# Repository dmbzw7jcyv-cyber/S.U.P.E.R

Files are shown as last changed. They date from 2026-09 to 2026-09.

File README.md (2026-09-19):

# S.U.P.E.R.

## Smart USB Peripheral Enclosure Rack

S.U.P.E.R. is a 3D-printable rack for **ten Crucial X10-sized portable SSDs**. It works as plain passive storage with zero electronics, then upgrades into a temperature-controlled rack using an Arduino Nano R4, a 120 mm PWM fan, temperature sensors, fan RPM monitoring, and optional physical SSD-presence switches.

Every SSD sits horizontally with its **USB-C port facing forward**, so a drive can remain in the rack while connected.

## v1 features

- 10 horizontal SSD bays in a 2 x 5 layout
- front-facing USB-C access
- finger-access openings
- rear mount for a standard 120 mm fan
- large airflow paths around the SSD matrix
- upper service compartment sized for an Arduino Nano R4
- hidden wiring channels
- optional removable microswitch carriers for bay detection
- optional rear fan grille
- removable electronics lid
- fully functional passive mode with no electronics installed

## Approximate size

The printed main body is about **124 x 124 x 80 mm**. A standard 25 mm-thick rear fan brings total depth to about **105 mm**.

## Reference electronics

- Arduino Nano R4
- Noctua NF-P12 redux-1700 PWM
- 1 to 3 DS18B20 temperature sensors
- 10 normally-open submini lever microswitches
- regulated 12 V power supply

## Repository layout

```text
S.U.P.E.R/
├── README.md
├── BOM.md
├── cad/
│   └── SUPER_v1.scad
├── stl/
│   ├── SUPER_main.stl
│   ├── SUPER_lid.stl
│   ├── SUPER_switch_carrier.stl
│   └── SUPER_fan_grille.stl
├── firmware/
│   └── SUPER_Controller/
│       └── SUPER_Controller.ino
└── docs/
    ├── WIRING.md
    └── PRINTING.md
```

The GitHub Action in `.github/workflows/build-stls.yml` regenerates the STL files from the OpenSCAD source.

## Build order

1. Print the main rack and lid.
2. Test a real X10 in several bays before installing electronics.
3. Mount the 120 mm fan on the rear as exhaust.
4. Install the Nano R4 in the upper service bay.
5. Wire fan power, PWM and tach according to `docs/WIRING.md`.
6. Add DS18B20 sensors and the required 4.7 kOhm pull-up.
7. If wanted, print two switch carriers and install the ten presence switches.
8. In Arduino IDE Library Manager, install **OneWire** and **DallasTemperature**.
9. Open `firmware/SUPER_Controller/SUPER_Controller.ino`.
10. Select **Arduino Nano R4**, compile and upload.
11. Open Serial Monitor at **115200 baud**.

## Default cooling curve

| Hottest sensor | Fan command |
|---|---:|
| <= 35 C | 0% |
| 35-40 C | 25% |
| 40-45 C | 50% |
| 45-50 C | 75% |
| > 50 C | 100% |

If temperature sensing fails, v1 commands **100% fan speed** as a fail-safe.

These are project defaults, not manufacturer thermal limits. Tune them only after testing your own enclosure, room temperature and workloads.

## Fan-control design

The fan is powered directly from the 12 V supply. **Do not power the fan from a Nano GPIO pin.** Nano D3 controls the blue PWM lead through a 2N2222/PN2222A NPN transistor used as an open-collector driver. The firmware generates a 25 kHz PWM waveform using the Nano R4 Renesas PWM API.

The fan green tach lead is read on D2 so the controller can report RPM.

## Bay detection

Each bay can press a normally-open microswitch when a drive is fully inserted. The switches share a ground bus and use the Nano's internal pull-ups.

This detects **physical presence only**. v1 does not inspect the SSD filesystem, SMART data, drive name, capacity or USB activity.

## Passive mode

Don't want to wire anything yet? Print the main rack and lid and use it immediately. The fan, Nano, temperature sensors and bay switches are optional upgrades and do not form part of the structural SSD slots.

## CAD

The editable source is `cad/SUPER_v1.scad`.

```bash
openscad -D 'part="main"' -o SUPER_main.stl cad/SUPER_v1.scad
openscad -D 'part="lid"' -o SUPER_lid.stl cad/SUPER_v1.scad
openscad -D 'part="switch_carrier"' -o SUPER_switch_carrier.stl cad/SUPER_v1.scad
openscad -D 'part="fan_grille"' -o SUPER_fan_grille.stl cad/SUPER_v1.scad
```

## Hardware references

- Arduino Nano R4: https://docs.arduino.cc/hardware/nano-r4/
- Noctua NF-P12 redux-1700 PWM: https://www.noctua.at/en/products/nf-p12-redux-1700-pwm
- Noctua PWM microcontroller guide: https://www.noctua.at/en/support/faqs/microcontroller-guide-pwm-setup-and-rpm-monitoring
- Crucial X10: https://www.crucial.com/ssd/x10

## Prototype warning

**v1 is a prototype design.** Measure your exact SSDs, switches, connectors and printed fit before assembling the complete electronics package. Insulate all connections, verify polarity with a multimeter, confirm the fan fail-safe works, and do not leave an early prototype powered unattended.

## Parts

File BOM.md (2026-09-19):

# S.U.P.E.R. v1 bill of materials

## Required for passive storage

| Qty | Part | Notes |
|---:|---|---|
| 1 | Printed `SUPER_main.stl` | Holds ten Crucial X10-sized portable SSDs |
| 1 | Printed `SUPER_lid.stl` | Covers the top electronics bay even if unused |

That is all you need if you only want the storage rack.

## Smart cooling upgrade

| Qty | Part | Notes |
|---:|---|---|
| 1 | Arduino Nano R4 with headers | Main controller |
| 1 | Noctua NF-P12 redux-1700 PWM | 120 mm, 12 V, 4-pin PWM fan |
| 1 | 12 V regulated supply, >=1 A | Powers fan and Nano VIN |
| 1 | 5.5 x 2.1 mm DC jack breakout | Or another suitable keyed connector |
| 1 | 2N2222 / PN2222A NPN transistor | Open-collector PWM interface |
| 1 | 1 kOhm resistor | Nano D3 to transistor base |
| 1 | 10 kOhm resistor | Transistor base pulldown |
| 1 | 4.7 kOhm resistor | DS18B20 data pull-up |
| 1 | 10 kOhm resistor | Optional external fan tach pull-up |
| 1-3 | DS18B20 sensors | Three zones recommended |
| 10 | Normally-open submini lever microswitches | Optional bay-presence detection |
| 2 | Printed switch carriers | One per five bays |
| 1 | Printed fan grille | Optional |
| 1 roll | 24-28 AWG hookup wire | Multiple colors strongly recommended |
| as needed | Heat shrink / crimp connectors | Insulate every exposed joint |

## Optional assembly hardware

- Four M4 machine screws + nuts long enough for your chosen fan/grille stack, or the fan's included mounting screws when appropriate
- Small JST-style connectors if you want the fan, sensors, and switch carriers to unplug cleanly
- Adhesive rubber feet for the bottom of the rack
- 1 A inline fuse on the 12 V input for extra protection

## Notes

The printed switch carrier targets switches around **12.8 x 6.5 x 6.5 mm**. Buy the switches first if possible and measure them with calipers before printing the carriers.

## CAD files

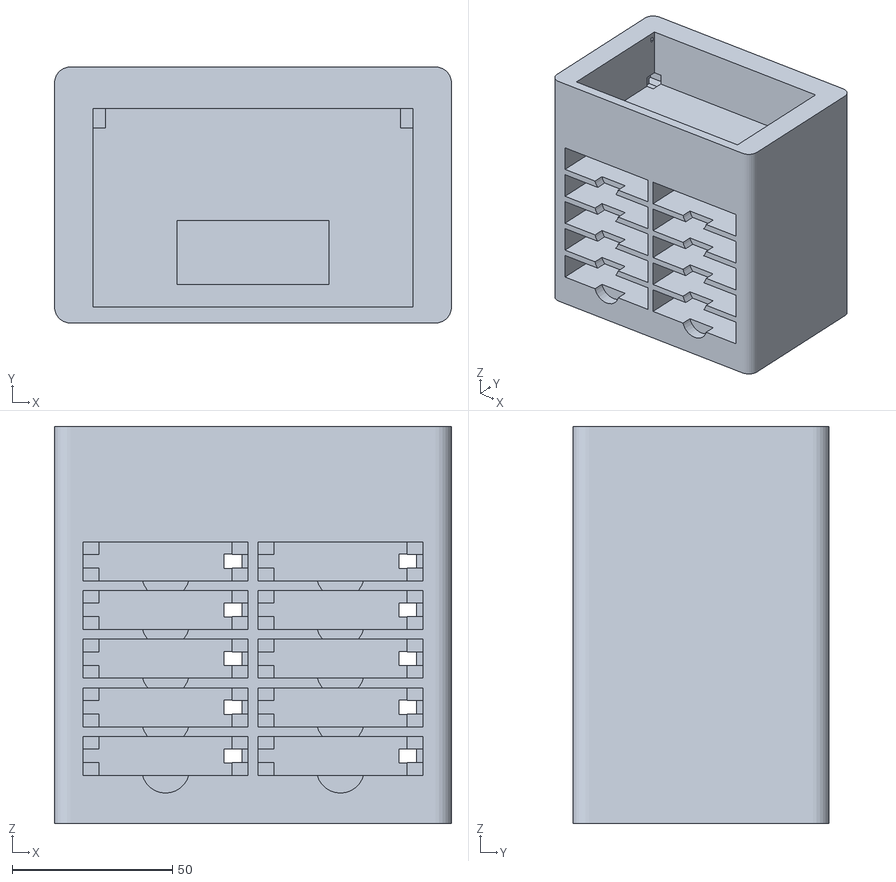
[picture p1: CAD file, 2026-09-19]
stl/SUPER_main.stl
124.0 x 80.0 x 124.0

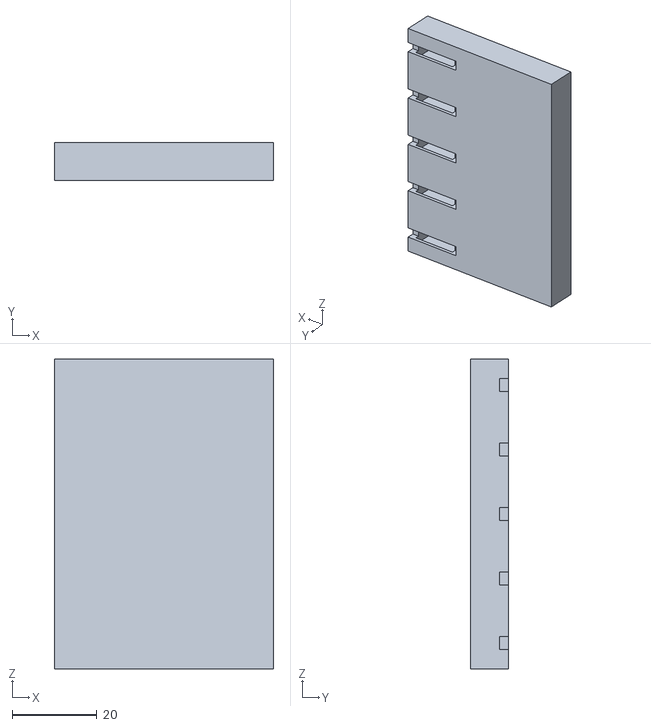
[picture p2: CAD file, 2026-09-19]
stl/SUPER_switch_carrier.stl
51.6 x 9.00 x 73.0

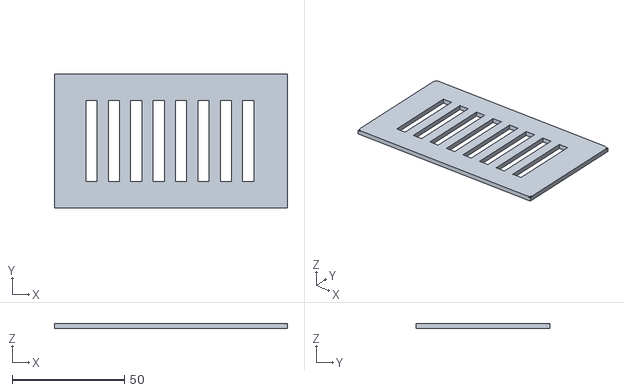
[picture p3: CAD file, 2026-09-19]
stl/SUPER_lid.stl
104.0 x 60.0 x 2.20

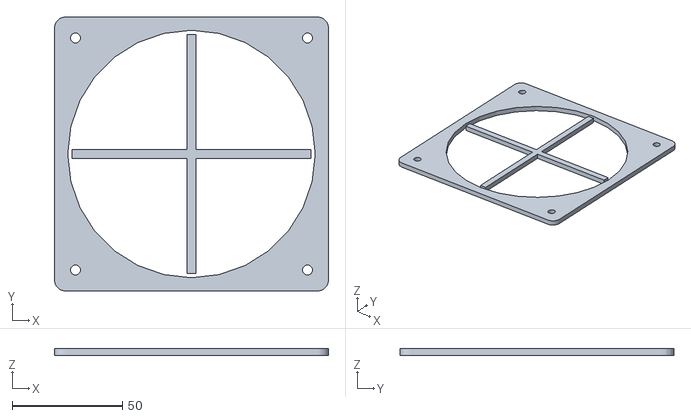
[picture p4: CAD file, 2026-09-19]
stl/SUPER_fan_grille.stl
124.0 x 124.0 x 3.00

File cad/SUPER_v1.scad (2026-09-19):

// S.U.P.E.R. v1
// Smart USB Peripheral Enclosure Rack
// 10 Crucial X10-sized SSD bays + optional Nano R4 smart cooling.
// Units: mm.
//
// Select part:
// openscad -D 'part="main"' -o SUPER_main.stl SUPER_v1.scad
// Parts: main, lid, switch_carrier, fan_grille

$fn = 28;
part = "main";

ssd_w = 50.0;
ssd_h = 10.0;
ssd_d = 65.0;
clear_w = 1.6;
clear_h = 2.2;
clear_d = 2.0;
bay_w = ssd_w + clear_w;
bay_h = ssd_h + clear_h;
bay_d = ssd_d + clear_d;

cols = 2;
rows = 5;
outer_w = 124;
outer_h = 124;
outer_d = 80;
wall = 3;
center_div = 3;
shelf = 3;
bay_stack_h = rows*bay_h + (rows-1)*shelf;
bay_x0 = (outer_w - (2*bay_w + center_div))/2;
bay_z0 = 15;

fan_hole_spacing = 105;
fan_hole_d = 4.5;
fan_center_x = outer_w/2;
fan_center_z = outer_h/2;

elec_z0 = 96;
elec_h = 25;
elec_y0 = 5;
elec_depth = 62;
nano_pocket_l = 47.5;
nano_pocket_w = 20.0;
nano_pocket_h = 9.0;
usb_cut_w = 12;
usb_cut_h = 8;

switch_body_l = 13.2;
switch_body_w = 7.0;
switch_body_h = 7.0;
carrier_w = bay_w;
carrier_d = 9;
carrier_h = bay_stack_h;

module rounded_box(size=[10,10,10], r=2) {
    linear_extrude(height=size[2])
        offset(r=r)
            offset(delta=-r)
                square([size[0], size[1]]);
}

module bay_cut(x,z) {
    translate([x, -0.2, z]) cube([bay_w, bay_d, bay_h]);

    translate([x + bay_w/2, 5.5, z + 2.0])
        rotate([90,0,0]) cylinder(h=6, r=7.5);

    translate([x+3, bay_d-0.1, z+2])
        cube([bay_w-6, outer_d-bay_d+0.3, bay_h-4]);

    translate([x + bay_w - 7.5, bay_d-0.6, z + bay_h/2 - 2.2])
        cube([5.5, 4.0, 4.4]);
}

module rear_stop_tabs(x,z) {
    tab_w = 5;
    tab_d = 4;
    tab_h = 4;
    translate([x-0.6, bay_d-tab_d, z])
        cube([tab_w+0.6,tab_d,tab_h]);
    translate([x+bay_w-tab_w, bay_d-tab_d, z])
        cube([tab_w+0.6,tab_d,tab_h]);
    translate([x-0.6, bay_d-tab_d, z+bay_h-tab_h])
        cube([tab_w+0.6,tab_d,tab_h]);
    translate([x+bay_w-tab_w, bay_d-tab_d, z+bay_h-tab_h])
        cube([tab_w+0.6,tab_d,tab_h]);
}

module fan_mount_holes() {
    for (sx=[-1,1], sz=[-1,1]) {
        x = fan_center_x + sx*fan_hole_spacing/2;
        z = fan_center_z + sz*fan_hole_spacing/2;
        translate([x, outer_d-8, z])
            rotate([-90,0,0]) cylinder(h=10,d=fan_hole_d);
    }
}

module wire_channels() {
    for (x=[3.5, outer_w-7.5]) {
        translate([x, bay_d+1, bay_z0-1])
            cube([4, outer_d-bay_d-2, bay_stack_h+4]);
    }
    translate([3.5, bay_d+1, elec_z0-4])
        cube([outer_w-7, outer_d-bay_d-2, 4]);
}

module electronics_cut() {
    translate([12, elec_y0, elec_z0])
        cube([outer_w-24, elec_depth, elec_h+5]);

    translate([outer_w/2 - nano_pocket_l/2,
               elec_y0 + 7,
               elec_z0 - 0.2])
        cube([nano_pocket_l, nano_pocket_w, nano_pocket_h]);

    translate([-0.2, elec_y0 + 12, elec_z0 + 7])
        cube([wall+1, usb_cut_w, usb_cut_h]);

    translate([8, elec_y0+elec_depth-6, elec_z0-3])
        cube([8,8,8]);
    translate([outer_w-16, elec_y0+elec_depth-6, elec_z0-3])
        cube([8,8,8]);
}

module lid_rails_cut() {
    translate([10, elec_y0+1, elec_z0+elec_h-1.6])
        cube([outer_w-20,1.8,2.2]);
    translate([10, elec_y0+elec_depth-2.8, elec_z0+elec_h-1.6])
        cube([outer_w-20,1.8,2.2]);
}

module main_rack() {
    difference() {
        rounded_box([outer_w,outer_d,outer_h], 5);

        for (r=[0:rows-1]) for (c=[0:cols-1]) {
            x = bay_x0 + c*(bay_w+center_div);
            z = bay_z0 + r*(bay_h+shelf);
            bay_cut(x,z);
        }

        translate([2.5,10,bay_z0+4])
            cube([bay_x0-4.5, outer_d-20, bay_stack_h-8]);
        translate([bay_x0+2*bay_w+center_div+2,10,bay_z0+4])
            cube([outer_w-(bay_x0+2*bay_w+center_div)-4.5,
                  outer_d-20,
                  bay_stack_h-8]);

        translate([bay_x0+1,bay_d-0.1,bay_z0+1])
            cube([2*bay_w+center_div-2,
                  outer_d-bay_d+0.3,
                  bay_stack_h-2]);

        wire_channels();
        electronics_cut();
        lid_rails_cut();
        fan_mount_holes();
    }

    for (r=[0:rows-1]) for (c=[0:cols-1]) {
        x = bay_x0 + c*(bay_w+center_div);
        z = bay_z0 + r*(bay_h+shelf);
        rear_stop_tabs(x,z);
    }
}

module electronics_lid() {
    lid_w = outer_w-20;
    lid_d = elec_depth-2;
    lid_t = 2.2;
    difference() {
        rounded_box([lid_w,lid_d,lid_t],2);
        for (i=[0:7])
            translate([14+i*10,12,-0.2])
                cube([5,lid_d-24,lid_t+0.4]);
    }
    translate([0,0,0]) cube([lid_w,1.4,1.8]);
    translate([0,lid_d-1.4,0]) cube([lid_w,1.4,1.8]);
}

module switch_carrier() {
    difference() {
        cube([carrier_w, carrier_d, carrier_h]);
        for (r=[0:rows-1]) {
            z = r*(bay_h+shelf) + (bay_h-switch_body_h)/2;
            translate([carrier_w-switch_body_l-2, 1.0, z])
                cube([switch_body_l, switch_body_w, switch_body_h]);
            translate([carrier_w-switch_body_l-4, carrier_d-2.2, z+2.0])
                cube([switch_body_l+4, 2.5, 3.0]);
        }
        translate([2,2,2])
            cube([3,carrier_d-3,carrier_h-4]);
    }
}

module fan_grille() {
    g=124;
    t=3;
    difference() {
        rounded_box([g,g,t],5);
        translate([g/2,g/2,-0.2])
            cylinder(h=t+0.4,d=112);
        for (sx=[-1,1], sy=[-1,1]) {
            x = g/2 + sx*fan_hole_spacing/2;
            y = g/2 + sy*fan_hole_spacing/2;
            translate([x,y,-0.2])
                cylinder(h=t+0.4,d=fan_hole_d);
        }
    }
    translate([g/2-2,8,0]) cube([4,g-16,t]);
    translate([8,g/2-2,0]) cube([g-16,4,t]);
}

if (part == "main") main_rack();
else if (part == "lid") electronics_lid();
else if (part == "switch_carrier") switch_carrier();
else if (part == "fan_grille") fan_grille();
else main_rack();

// STL build trigger: v1

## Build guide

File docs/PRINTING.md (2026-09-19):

# Printing and assembly

## Files

- `stl/SUPER_main.stl` - main 10-bay rack and rear fan mount
- `stl/SUPER_lid.stl` - electronics-compartment lid
- `stl/SUPER_switch_carrier.stl` - optional five-switch carrier; print two
- `stl/SUPER_fan_grille.stl` - optional rear fan guard
- `cad/SUPER_v1.scad` - editable source

## Main dimensions

The body is approximately **124 x 124 x 80 mm**. A 25 mm-thick 120 mm fan mounted on the rear brings total depth to about **105 mm**.

The current SSD cavities use an approximately **65 x 50 x 10 mm** X10 envelope plus print and airflow clearance. Verify against your own drive before a long print.

## Suggested settings

- Material: PETG preferred; PLA+ is fine for ordinary indoor temperatures
- Layer height: 0.20 mm
- Walls/perimeters: 4
- Top/bottom layers: 4 or 5
- Infill: 15 to 25%
- Nozzle: 0.4 mm

For the main body, orient the model so the **front face is on the build plate**. This makes the long SSD cavities build vertically rather than requiring giant horizontal bridges.

The smaller parts can print flat on their largest face.

## Fit-test first

Printers vary. Before committing to the full rack, make a small one-bay test or crop the model in your slicer. An X10 should slide in without force but should not rattle dramatically.

If your printer runs tight, increase `clear_w` and `clear_h` in `cad/SUPER_v1.scad` by about 0.2 to 0.4 mm.

## Fan orientation

Mount the fan at the rear as **exhaust**. It should pull room air through the open front/side passages, across the SSDs, and out the back.

The model uses a standard **105 x 105 mm** 120 mm fan mounting pattern.

## Electronics bay

The top service compartment is separate from the SSD tunnels and includes:

- Nano-R4-sized pocket
- side USB-C programming opening
- wiring pass-throughs to the rear cable spines
- removable vented lid

The rack still works with this compartment totally empty.

## Presence sensors

Print **two** switch carriers if you want smart bay detection. Each holds five switches.

Microswitch dimensions vary by manufacturer. If yours do not fit, change only the `switch_body_*` parameters in the SCAD and re-export the carrier.

## Fan grille

The rear grille is optional. If installed, use fasteners long enough for your fan/grille arrangement but never allow screw tips to contact the blades.

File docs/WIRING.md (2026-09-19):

# S.U.P.E.R. wiring guide

The printed rack works as passive storage with **none of this electronics installed**.

## Important electrical rule

**Do not power the 12 V fan from an Arduino GPIO pin or the Nano's 5 V pin.** The fan receives 12 V directly from the power supply. The Nano only controls the PWM lead and reads the tach lead.

The reference fan is the **Noctua NF-P12 redux-1700 PWM**. Noctua specifies it as a 120 x 120 x 25 mm, 12 V, 4-pin PWM fan with 105 mm mounting-hole spacing.

| Fan pin | Noctua wire | Connect to |
|---|---|---|
| 1 | Black | Common GND |
| 2 | Yellow | +12 V supply |
| 3 | Green | Nano D2 (tach) |
| 4 | Blue | Collector of NPN PWM transistor |

## Controller parts

- Arduino Nano R4
- 1x 2N2222 / PN2222A NPN transistor
- 1x 1 kOhm base resistor
- 1x 10 kOhm base pulldown resistor
- 1x optional 10 kOhm tach pull-up to +5 V
- 1x 4.7 kOhm DS18B20 data pull-up
- 1 to 3x DS18B20 temperature sensors
- 10x normally-open submini lever microswitches
- 12 V regulated supply, at least 1 A
- 24 to 28 AWG hookup wire
- heat-shrink tubing or insulated crimp connectors

## Power

The Nano R4 VIN input accepts the 12 V supply used by the reference build.

```text
12 V adapter +  --------------------+---------------- Fan YELLOW (+12 V)
                                    |
                                    +---------------- Nano R4 VIN

12 V adapter GND -------------------+---------------- Fan BLACK (GND)
                                    |
                                    +---------------- Nano R4 GND
                                    |
                                    +---------------- Sensor/switch GND bus
```

All grounds must be common.

If you later add a display, many LEDs, or other accessories, a small 12 V to 5 V buck converter is a good optional upgrade to reduce heat in the Nano's onboard regulator.

## Fan PWM interface

Use an **open-collector NPN stage** rather than connecting the blue PWM wire straight to the GPIO.

```text
Nano D3 ---- 1k ---- B   2N2222
                       C ---------------- Fan BLUE (PWM)
Nano GND -------------- E

10k resistor from B to GND
```

The 10 kOhm pulldown holds the transistor OFF during reset/boot. That lets the fan PWM input float HIGH through the fan's internal circuitry, giving a fail-safe full-speed command while the microcontroller is not actively driving the line.

The firmware outputs approximately **25 kHz PWM** and automatically handles the inversion caused by the NPN stage.

## Fan tach / RPM

```text
Fan GREEN (tach) ---------------- Nano D2
Fan BLACK (ground) -------------- Nano GND

Optional: 10k resistor from D2 to +5 V
```

Noctua specifies the tach output as open-collector with **two cycles per revolution**. The firmware uses that value for RPM calculation.

## Temperature sensors

All DS18B20 sensors share one 1-Wire bus.

```text
DS18B20 VDD   ---------------- +5 V
DS18B20 GND   ---------------- GND
DS18B20 DATA  ---------------- Nano D6

4.7k resistor between DATA and +5 V
```

Suggested sensor locations:

1. lower SSD bank
2. center of the SSD matrix
3. upper/rear exhaust area

The firmware uses the hottest valid sensor reading.

## SSD presence switches

Each bay uses one normally-open microswitch. One terminal of every switch shares ground; the other goes to a dedicated Nano input.

| Bay | Nano pin |
|---|---|
| 1 | D4 |
| 2 | D5 |
| 3 | D7 |
| 4 | D8 |
| 5 | D9 |
| 6 | D10 |
| 7 | D11 |
| 8 | D12 |
| 9 | D13 |
| 10 | A0 |

```text
Nano input ---- microswitch ---- GND
```

The firmware uses `INPUT_PULLUP`:

- switch open = empty bay
- switch pressed = occupied bay

The optional CAD switch carrier targets switches around **12.8 x 6.5 x 6.5 mm**. Measure your actual switches before printing ten of anything.

## SSD data cables

S.U.P.E.R. v1 is **not a USB hub**. Each SSD keeps its own front-facing USB-C port. Connect drives directly to the computer or to a suitable powered USB hub.

The Nano detects physical insertion only. It does not read the drive name, filesystem, SMART health, capacity or USB activity.

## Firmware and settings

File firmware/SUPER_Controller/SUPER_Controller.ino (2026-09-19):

/*
  S.U.P.E.R. Controller
  Smart USB Peripheral Enclosure Rack

  Target: Arduino Nano R4
  Fan: 4-wire 12 V PWM PC fan
  Sensors: up to 3 DS18B20 temperature sensors on one 1-Wire bus
  Bay detection: 10 normally-open microswitches, active LOW with INPUT_PULLUP

  IMPORTANT:
  - The fan's 12 V power does NOT come from the Nano.
  - The Nano controls the fan PWM lead through an NPN open-collector stage.
  - Fan and Nano grounds MUST be common.
  - A 10k base pulldown keeps the transistor OFF while the Nano boots,
    so the fan PWM input floats HIGH and defaults to full speed.
*/

#include <Arduino.h>
#include <OneWire.h>
#include <DallasTemperature.h>
#include "pwm.h"

constexpr uint8_t FAN_PWM_PIN  = D3;
constexpr uint8_t FAN_TACH_PIN = D2;
constexpr uint8_t TEMP_PIN     = D6;

const uint8_t BAY_PINS[10] = {
  D4, D5, D7, D8, D9,
  D10, D11, D12, D13, A0
};

constexpr float FAN_PWM_FREQUENCY_HZ = 25000.0f;
constexpr uint8_t TACH_PULSES_PER_REV = 2;
constexpr uint16_t RPM_SAMPLE_MS = 1000;
constexpr bool FAILSAFE_FULL_SPEED_ON_TEMP_ERROR = true;

constexpr float T0 = 35.0f;
constexpr float T1 = 40.0f;
constexpr float T2 = 45.0f;
constexpr float T3 = 50.0f;

OneWire oneWire(TEMP_PIN);
DallasTemperature tempBus(&oneWire);
PwmOut fanPwm(FAN_PWM_PIN);

volatile uint32_t tachPulses = 0;
uint32_t lastRpmSample = 0;
uint32_t lastStatusPrint = 0;
uint16_t currentRpm = 0;
float currentFanPercent = 100.0f;
float currentMaxTempC = NAN;
uint8_t currentOccupied = 0;

void tachISR() {
  tachPulses++;
}

uint8_t countOccupiedBays() {
  uint8_t count = 0;
  for (uint8_t i = 0; i < 10; ++i) {
    if (digitalRead(BAY_PINS[i]) == LOW) count++;
  }
  return count;
}

float readMaxTemperatureC() {
  tempBus.requestTemperatures();
  const uint8_t count = tempBus.getDeviceCount();
  if (count == 0) return NAN;

  float maxTemp = -1000.0f;
  bool foundValid = false;
  const uint8_t n = (count < 3) ? count : 3;

  for (uint8_t i = 0; i < n; ++i) {
    const float t = tempBus.getTempCByIndex(i);
    if (t != DEVICE_DISCONNECTED_C && t > -55.0f && t < 125.0f) {
      if (t > maxTemp) maxTemp = t;
      foundValid = true;
    }
  }

  return foundValid ? maxTemp : NAN;
}

float fanCurve(float tempC) {
  if (isnan(tempC)) {
    return FAILSAFE_FULL_SPEED_ON_TEMP_ERROR ? 100.0f
                                             : (currentOccupied ? 35.0f : 0.0f);
  }

  if (tempC <= T0) return 0.0f;
  if (tempC <= T1) return 25.0f;
  if (tempC <= T2) return 50.0f;
  if (tempC <= T3) return 75.0f;
  return 100.0f;
}

void setFanPercent(float requestedPercent) {
  requestedPercent = constrain(requestedPercent, 0.0f, 100.0f);

  // NPN stage inverts the logic:
  // Nano HIGH -> transistor ON -> fan PWM lead LOW.
  // Nano LOW  -> transistor OFF -> fan internal pull-up HIGH.
  const float transistorDuty = 100.0f - requestedPercent;
  fanPwm.pulse_perc(transistorDuty);
  currentFanPercent = requestedPercent;
}

void updateRpm() {
  const uint32_t now = millis();
  if (now - lastRpmSample < RPM_SAMPLE_MS) return;

  noInterrupts();
  const uint32_t pulses = tachPulses;
  tachPulses = 0;
  interrupts();

  const float elapsedSeconds = (now - lastRpmSample) / 1000.0f;
  lastRpmSample = now;

  if (elapsedSeconds > 0.0f) {
    currentRpm = (uint16_t)((pulses * 60.0f) /
                            (TACH_PULSES_PER_REV * elapsedSeconds));
  }
}

void printStatus() {
  const uint32_t now = millis();
  if (now - lastStatusPrint < 2000) return;
  lastStatusPrint = now;

  Serial.println(F("\n--- S.U.P.E.R. STATUS ---"));
  Serial.print(F("Bays occupied: "));
  Serial.print(currentOccupied);
  Serial.println(F(" / 10"));

  Serial.print(F("Bay map: "));
  for (uint8_t i = 0; i < 10; ++i) {
    Serial.print(digitalRead(BAY_PINS[i]) == LOW ? F("[X]") : F("[ ]"));
  }
  Serial.println();

  Serial.print(F("Max temperature: "));
  if (isnan(currentMaxTempC)) {
    Serial.println(F("SENSOR ERROR"));
  } else {
    Serial.print(currentMaxTempC, 1);
    Serial.println(F(" C"));
  }

  Serial.print(F("Fan command: "));
  Serial.print(currentFanPercent, 0);
  Serial.println(F(" %"));

  Serial.print(F("Fan RPM: "));
  Serial.println(currentRpm);
}

void setup() {
  Serial.begin(115200);
  delay(300);
  Serial.println(F("S.U.P.E.R. controller starting..."));

  for (uint8_t i = 0; i < 10; ++i) {
    pinMode(BAY_PINS[i], INPUT_PULLUP);
  }

  pinMode(FAN_TACH_PIN, INPUT_PULLUP);
  attachInterrupt(digitalPinToInterrupt(FAN_TACH_PIN), tachISR, FALLING);

  tempBus.begin();
  tempBus.setResolution(10);

  if (!fanPwm.begin(FAN_PWM_FREQUENCY_HZ, 0.0f)) {
    Serial.println(F("ERROR: Could not start fan PWM timer."));
  }

  currentOccupied = countOccupiedBays();
  currentMaxTempC = readMaxTemperatureC();
  setFanPercent(fanCurve(currentMaxTempC));

  lastRpmSample = millis();
}

void loop() {
  currentOccupied = countOccupiedBays();
  currentMaxTempC = readMaxTemperatureC();
  setFanPercent(fanCurve(currentMaxTempC));

  updateRpm();
  printStatus();

  delay(500);
}

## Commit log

2026-09-19 Add S.U.P.E.R. bill of materials
2026-09-19 Add wiring and power guide
2026-09-19 Add printing and assembly guide
2026-09-19 Add parametric S.U.P.E.R. enclosure CAD
    [SUPER_v1.scad]
2026-09-19 Automate STL generation
2026-09-19 Trigger STL build for v1
    [SUPER_v1.scad]
2026-09-19 Build STL files
    [SUPER_fan_grille.stl, SUPER_lid.stl, SUPER_main.stl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]
